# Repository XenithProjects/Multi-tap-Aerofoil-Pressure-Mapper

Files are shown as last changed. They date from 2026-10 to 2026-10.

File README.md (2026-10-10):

# Multi-tap-Aerofoil-Pressure-Mapper
An open-source Multi-tap Aerofoil Pressure Mapper for a NACA 2412 Aerofoil using an ESP32, a PCA9548A I2C Multiplexer and five Sensirion SDP810-500Pa differential pressure sensors.
Adaptable to other aerofoil designs.

20260806_193753(1)

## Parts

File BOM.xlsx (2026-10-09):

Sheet: Sheet1
# | Component | Specification | Qty | Unit (S$) | Total (S$) | Source | Purchased?
1 | ESP32 DevKit V1 | 38-pin, 240 MHz, Wi-Fi + BT, USB-serial | 1 | 4.3 | 4.3 | Taobao | Yes
2 | I2C Multiplexer | TCA9548A breakout, 8-channel | 1 | 0.87 | 0.87 | Taobao | Yes
3 | Sensirion SDP810-125Pa | ±125 Pa, I2C, 16-bit — upper surface taps (U1–U5) | 5 | 12.97 | 64.85 | Taobao
4 | Sensirion SDP810-125Pa | ±125 Pa, I2C — freestream pitot reference | 1 | 12.97 | 12.97 | Taobao
5 | NACA 2412 model (3D print) | PLA, 200 mm chord × 100 mm span, 5 taps pre-modelled | 1 | 0 | 0 | Home
6 | Brass tube stubs | OD 1.5 mm, cut to 10 mm — tap stubs × 8 | 8 | 0.3 | 2.4 | Sim Lim / hardware
7 | Vinyl tubing | ID 1 mm, 3 m roll — tap-to-sensor lines | 1 | 4 | 4 | Shopee
8 | Epoxy adhesive | 2-part low-viscosity, for tap stub sealing | 1 | 3.5 | 3.5 | Hardware store
9 | Breadboard + jumper kit | 830-tie full breadboard + 65-piece jumper set | 1 | 4.34 | 4.34 | Taobao
10 | 4.7 kΩ resistors | Through-hole, I2C pull-ups × 10 | 1 |  | 0
11 | 100 nF decoupling caps | Ceramic through-hole × 10 | 1 |  | 0
12 | USB Micro-B cable | Data + power, 1 m | 1 | 0 | 0 | Home
13 | 5 V USB adapter | 1 A minimum for ESP32 | 1 | 0 | 0 | Home
14 | MicroSD card module + card | SPI, 8 GB card — for offline data logging | 1 | 0.72 | 0.72 | Taobao
15 | Adjustable AoA stand | 3D-printed, protractor scale, ±20° range | 1 | 0 | 0 | Home
16 | Duct fan / desk fan | ≥ 15 m/s freestream at model — borrow if possible | 1 | 0 | 0 | Home
TOTAL ESTIMATED COST |  |  |  |  | 97.95 | Under S$100 budget ✓

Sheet: Sheet2
# | Component | Qty | Unit (S$) | Total (S$) | Source | Purchased?
1 | ESP32-WROOM-32 DevKit V1 | 1
2 | Sensirion SDP810-500Pa - upper taps U1 to U5, lower taps L1 & L2, freestream pitot static reference | 8
5 | PCA9548A 8-channel I2C multiplexer breakout module | 1
6 | NACA 2412 aerofoil model - 3D-printed | 1
7 | Brass tube stubs - OD 1.5 mm, ID 0.8 mm, cut to 10 mm | 16
8 | Vinyl tubing - ID 1 mm, OD 2 mm, 3 m roll | 1
9 | 2-part low-viscosity epoxy adhesive (Araldite Rapid) | 1
10 | Half-size solderless breadboard - 400-tie | 1
11 | Jumper wire kit - male-male and male-female, 65 pieces | 1
12 | 4.7 kOhm resistors | 2
13 | 100 nF ceramic capacitors | 8
14 | 10 uF electrolytic capacitors | 2
15 | USB C cable - 1 m, data-capable | 1
17 | Adjustable angle-of-attack stand - 3D-printed | 1
18 | Pitot tube assembly - 3D-printed | 1
20 | Duct fan or desk fan - minimum 15 m/s freestream velocity at model face | 1
TOTAL ESTIMATED COST |  |  |  | 0 | S$14.32 under budget

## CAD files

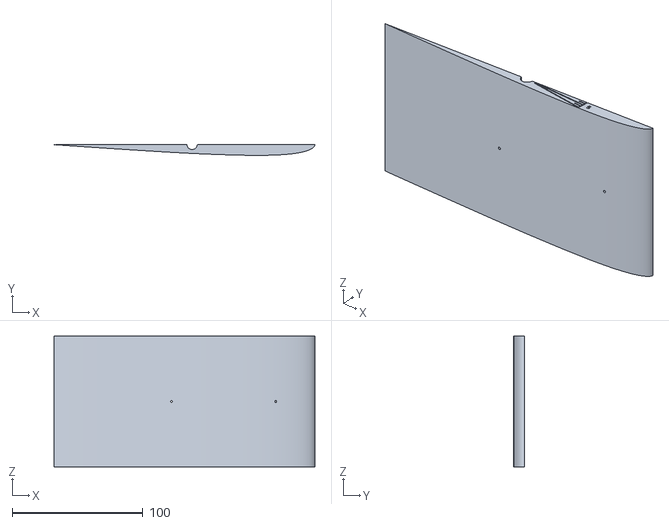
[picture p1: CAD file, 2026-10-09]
.stl Files/Aerofoil w Angle Stand/NACA2412 Airfoil_Lower.stl
199.9 x 8.23 x 100.0

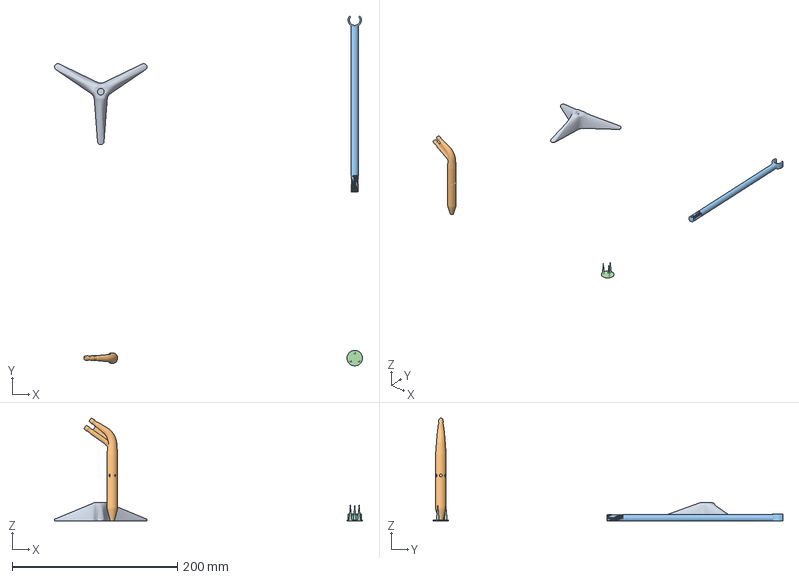
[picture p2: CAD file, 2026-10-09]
.stl Files/Pitot-static Probe.3mf
372.5 x 423.0 x 124.3 mm
Tripod.stl
Pitot-static Head.stl
Stem.stl
string test.stl

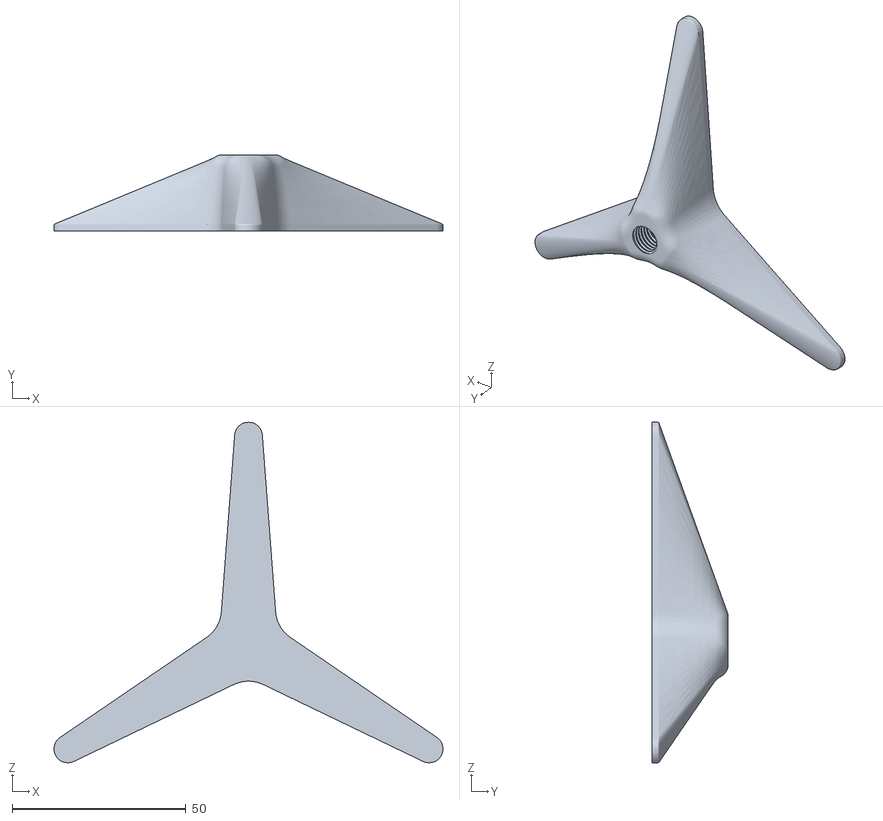
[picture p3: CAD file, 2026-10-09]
.stl Files/Pitot-static Tube/Tripod.stl
111.9 x 22.0 x 98.0

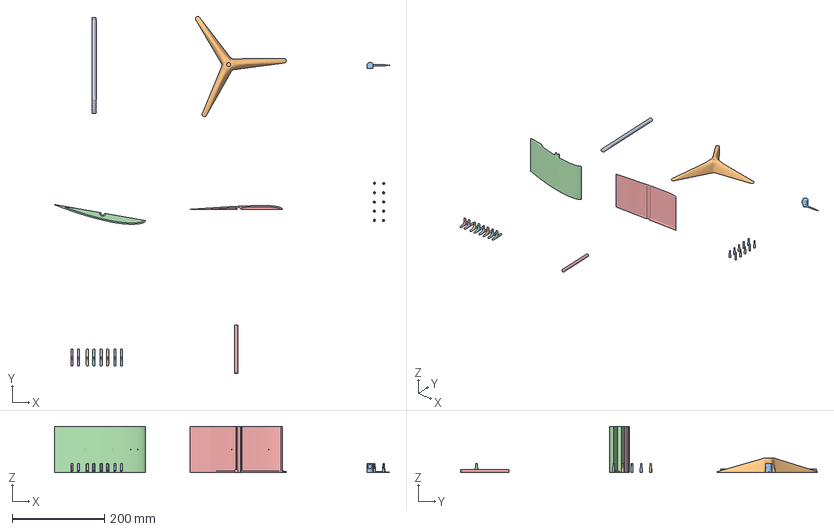
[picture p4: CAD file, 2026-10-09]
.stl Files/Aerofoil w Angle Stand.3mf
724.5 x 773.0 x 100.0 mm
Stem_AF.stl
Tripod_AF.stl
Pointer Joint.stl
NACA2412 Airfoil_Upper.stl
NACA2412 Airfoil_Lower.stl
Vtube Adapter_v3.stl x 10
Vtube T-joint.stl x 8
Dowel_v3.stl

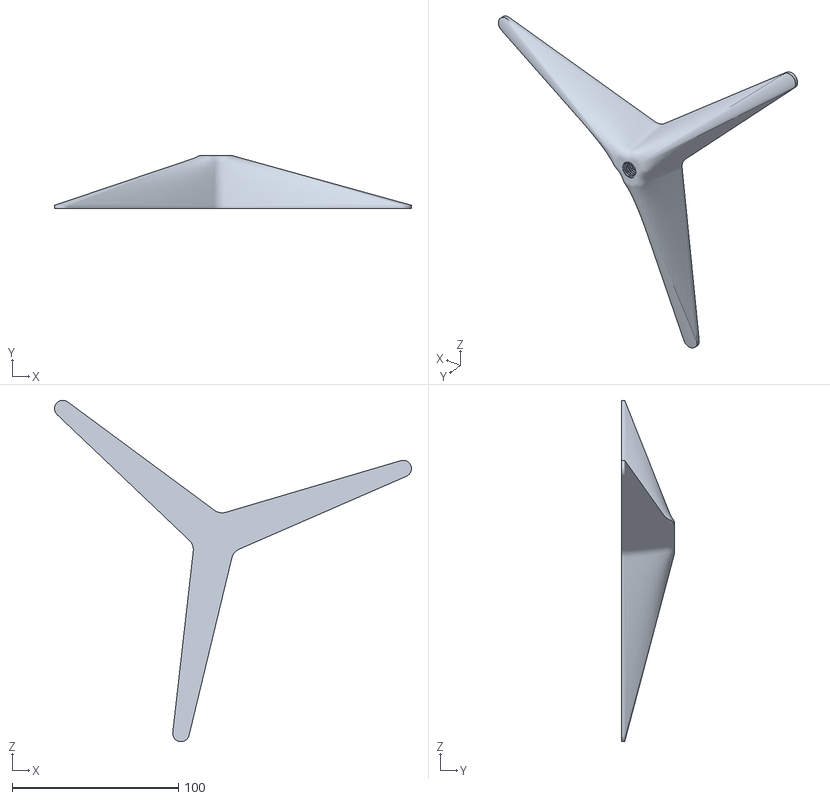
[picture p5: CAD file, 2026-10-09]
.stl Files/Aerofoil w Angle Stand/Tripod_AF.stl
214.7 x 32.0 x 205.3

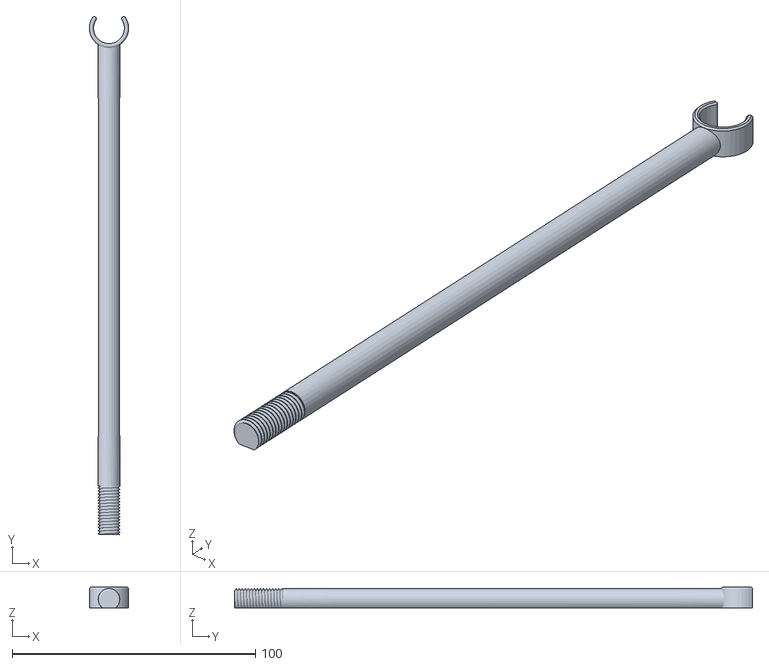
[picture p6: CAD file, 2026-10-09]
.stl Files/Pitot-static Tube/Stem.stl
16.2 x 212.9 x 8.50

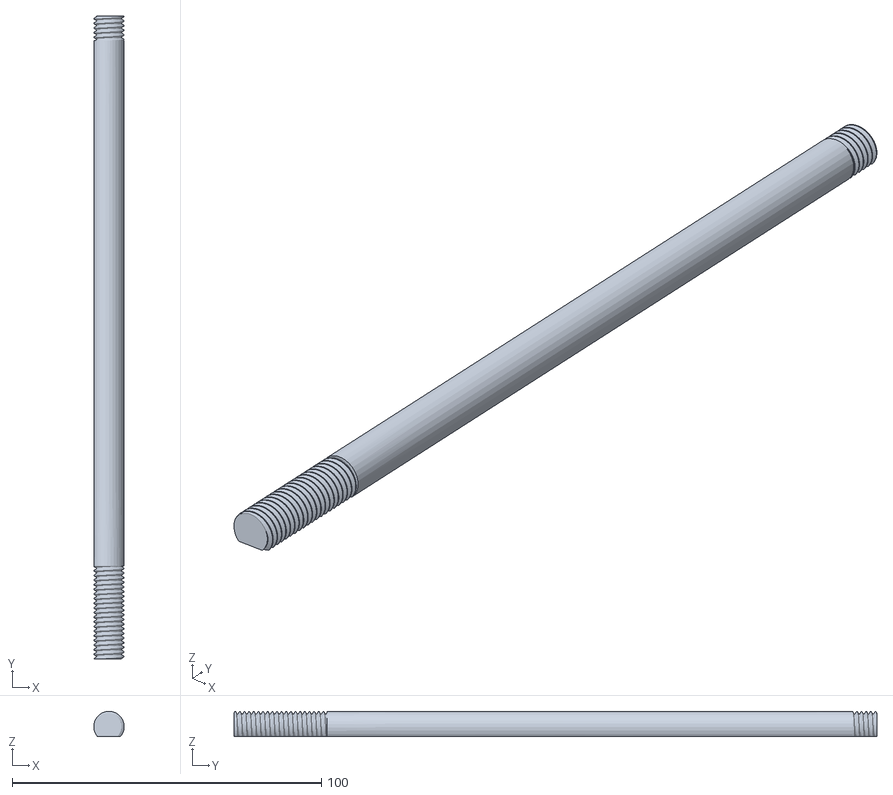
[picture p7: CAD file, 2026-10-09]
.stl Files/Aerofoil w Angle Stand/Stem_AF.stl
9.85 x 207.9 x 8.18

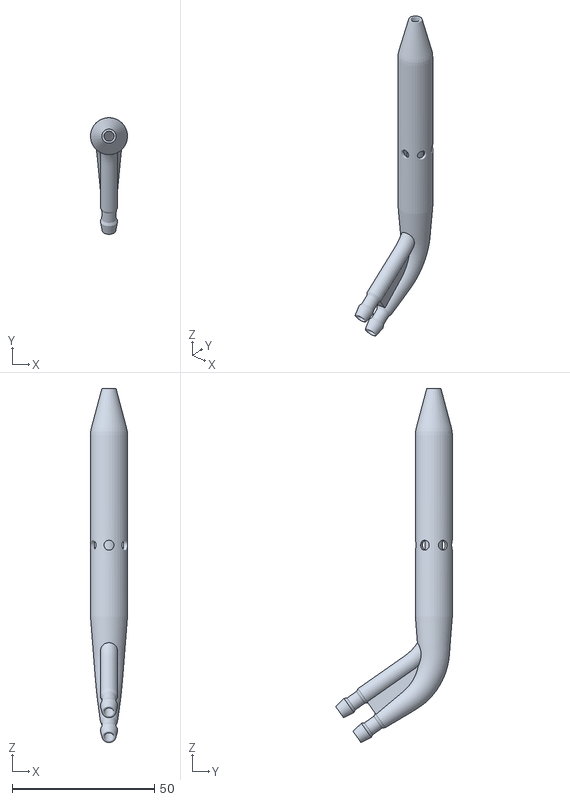
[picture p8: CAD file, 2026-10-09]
.stl Files/Pitot-static Tube/Pitot-static Head.stl
13.0 x 41.0 x 124.3

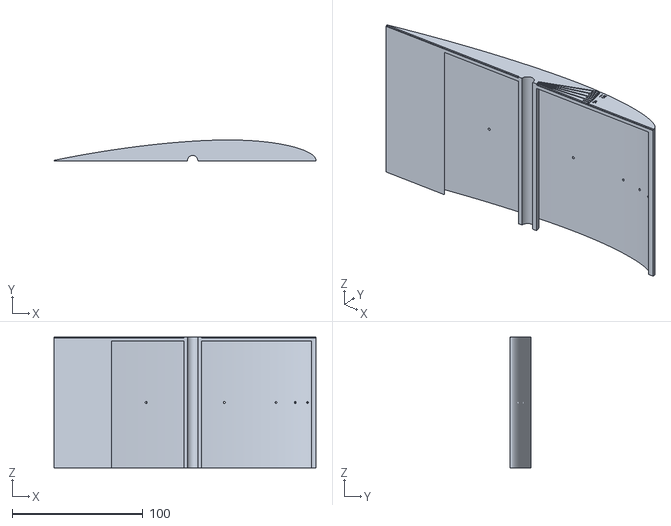
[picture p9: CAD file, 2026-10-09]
.stl Files/Aerofoil w Angle Stand/NACA2412 Airfoil_Upper.stl
200.0 x 16.1 x 100.0

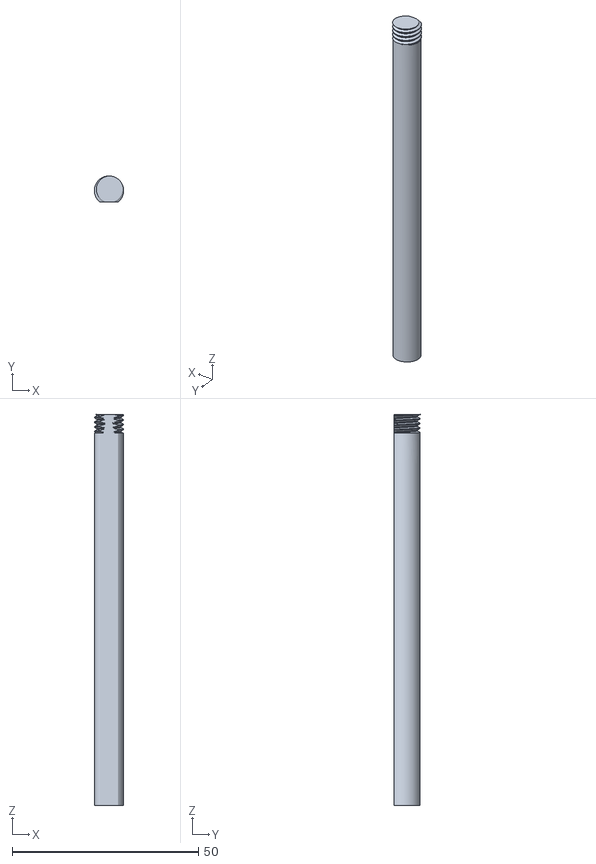
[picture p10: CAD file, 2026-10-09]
.stl Files/Aerofoil w Angle Stand/Dowel_v3.stl
7.87 x 7.02 x 104.9

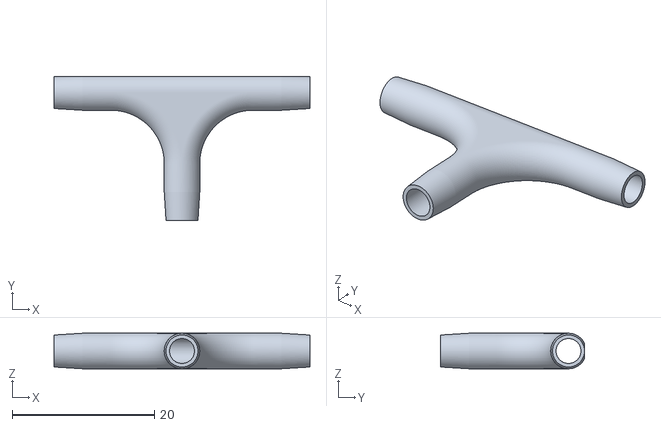
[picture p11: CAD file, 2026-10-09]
.stl Files/Aerofoil w Angle Stand/Vtube T-joint.stl
36.0 x 20.2 x 5.00

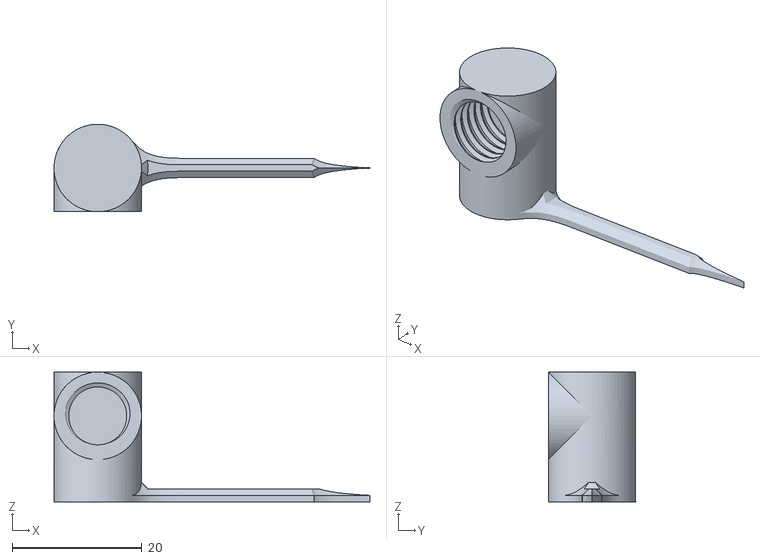
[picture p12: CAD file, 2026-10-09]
.stl Files/Aerofoil w Angle Stand/Pointer Joint.stl
48.8 x 13.5 x 20.0

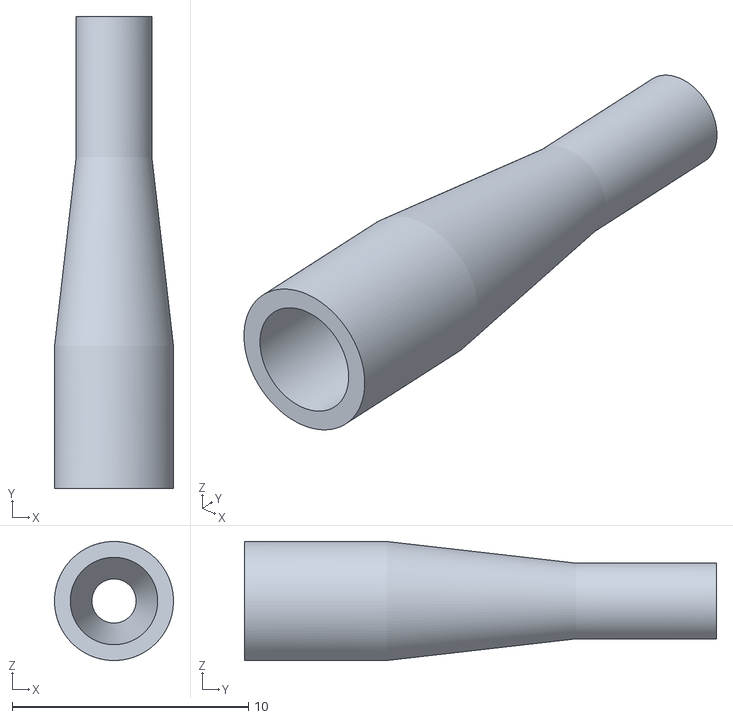
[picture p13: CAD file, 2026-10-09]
.stl Files/Aerofoil w Angle Stand/Vtube Adapter_v3.stl
5.04 x 20.0 x 5.04

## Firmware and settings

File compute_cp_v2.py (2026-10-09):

"""
compute_cp.py

Reads a CSV logged by serial_logger.py (columns: time_ms, P_ch0..P_ch5)
and computes the pressure coefficient Cp at each tap.

Assumes:
  - CH0-CH4 (or however many taps you have wired) are surface pressure taps,
    each measuring (P_tap - P_static_reference).
  - CH5 is the pitot channel, measuring (P_total - P_static_reference) = dynamic
    pressure q_inf, since it shares the same static reference line as the taps.
  - Cp = P_tap_measured / q_inf   (since both sensors reference the same static line,
    the P_static term cancels out algebraically).

Adjust TAP_CHANNELS / PITOT_CHANNEL / tap x/c labels below to match your actual
wiring order before running.

Usage:
    python compute_cp.py aerofoil_run_20260803_143000.csv
    python compute_cp.py aerofoil_run_20260803_143000.csv --start 5 --end 25
"""

import argparse
import sys

import pandas as pd
import matplotlib.pyplot as plt

# --- Configure this to match your actual tap layout ---
# Updated layout: CH0=U1, CH1=U2, CH2=U3, CH3=L1, CH4=REF (pitot). CH5 unused (faulty sensor).
PITOT_CHANNEL = "P_ch4"
TAP_CHANNELS = {
    "P_ch0": {"label": "U1", "surface": "upper", "x_c": 0.025},
    "P_ch1": {"label": "U2", "surface": "upper", "x_c": 0.150},
    "P_ch2": {"label": "U3", "surface": "upper", "x_c": 0.350},
    "P_ch3": {"label": "L1", "surface": "lower", "x_c": 0.150},
}


def main():
    parser = argparse.ArgumentParser(description="Compute Cp distribution from logged sensor data.")
    parser.add_argument("csv_file", help="Path to CSV file from serial_logger.py")
    parser.add_argument("--start", type=float, default=None,
                         help="Start of steady-state averaging window, in seconds from log start")
    parser.add_argument("--end", type=float, default=None,
                         help="End of steady-state averaging window, in seconds from log start")
    parser.add_argument("--out", default="cp_results.csv", help="Output CSV filename for Cp results")
    parser.add_argument("--no-plot", action="store_true", help="Skip generating the Cp plot")
    args = parser.parse_args()

    df = pd.read_csv(args.csv_file)
    df["time_s"] = (df["time_ms"] - df["time_ms"].iloc[0]) / 1000.0

    # Trim to steady-state window if given
    if args.start is not None:
        df = df[df["time_s"] >= args.start]
    if args.end is not None:
        df = df[df["time_s"] <= args.end]

    if df.empty:
        print("No data left after applying --start/--end window. Check your time range.")
        sys.exit(1)

    print(f"Averaging over {len(df)} rows "
          f"({df['time_s'].min():.1f}s to {df['time_s'].max():.1f}s)\n")

    q_inf = df[PITOT_CHANNEL].mean()
    q_std = df[PITOT_CHANNEL].std()
    print(f"Freestream dynamic pressure q_inf = {q_inf:.3f} Pa (std dev {q_std:.3f} Pa)")

    if q_inf <= 0:
        print("WARNING: q_inf is zero or negative - check pitot wiring/orientation, "
              "or that airflow is actually running.")

    results = []
    for ch, meta in TAP_CHANNELS.items():
        if ch not in df.columns:
            print(f"WARNING: {ch} not found in CSV columns, skipping.")
            continue

        p_mean = df[ch].mean()
        p_std = df[ch].std()
        cp = p_mean / q_inf if q_inf else float("nan")

        results.append({
            "channel": ch,
            "label": meta["label"],
            "surface": meta["surface"],
            "x_c": meta["x_c"],
            "P_mean_Pa": round(p_mean, 3),
            "P_std_Pa": round(p_std, 3),
            "Cp": round(cp, 4),
        })

    results_df = pd.DataFrame(results).sort_values(["surface", "x_c"])
    print("\n--- Cp Results ---")
    print(results_df.to_string(index=False))

    results_df.to_csv(args.out, index=False)
    print(f"\nSaved results to {args.out}")

    if not args.no_plot:
        fig, ax = plt.subplots(figsize=(7, 5))
        for surface, marker in [("upper", "o-"), ("lower", "s-")]:
            sub = results_df[results_df["surface"] == surface]
            if not sub.empty:
                ax.plot(sub["x_c"], sub["Cp"], marker, label=f"{surface} surface")

        ax.invert_yaxis()  # aerodynamic convention: Cp axis flipped
        ax.set_xlabel("x/c")
        ax.set_ylabel("Cp")
        ax.set_title("NACA 2412 Pressure Distribution")
        ax.legend()
        ax.grid(True, alpha=0.3)
        fig.tight_layout()

        plot_file = args.out.replace(".csv", "_plot.png")
        fig.savefig(plot_file, dpi=150)
        print(f"Saved plot to {plot_file}")


if __name__ == "__main__":
    main()

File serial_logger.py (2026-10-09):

"""
serial_logger.py

Logs CSV pressure data streamed from the ESP32 (aerofoil_scanner_serial.ino)
to a local CSV file, for later Cp post-processing.

Requires: pip install pyserial

Usage:
    python serial_logger.py --port COM5
    python serial_logger.py --port /dev/ttyUSB0 --duration 30
"""

import argparse
import csv
import sys
import time
from datetime import datetime

import serial


def main():
    parser = argparse.ArgumentParser(description="Log SDP810 mux data over serial to CSV.")
    parser.add_argument("--port", required=True, help="Serial port, e.g. COM5 or /dev/ttyUSB0")
    parser.add_argument("--baud", type=int, default=115200, help="Baud rate (default 115200)")
    parser.add_argument("--outfile", default=None, help="Output CSV filename")
    parser.add_argument("--duration", type=float, default=None,
                         help="Seconds to log before auto-stopping (default: run until Ctrl+C)")
    args = parser.parse_args()

    outfile = args.outfile or f"aerofoil_run_{datetime.now().strftime('%Y%m%d_%H%M%S')}.csv"

    print(f"Connecting to {args.port} at {args.baud} baud...")
    ser = serial.Serial(args.port, args.baud, timeout=1)
    time.sleep(2)  # allow ESP32 to reset after serial connection opens

    header_written = False
    start_time = time.time()
    row_count = 0

    with open(outfile, "w", newline="") as f:
        writer = csv.writer(f)
        print(f"Logging to {outfile} ... Ctrl+C to stop\n")

        try:
            while True:
                if args.duration is not None and (time.time() - start_time) > args.duration:
                    print(f"\nReached duration limit of {args.duration}s, stopping.")
                    break

                raw = ser.readline().decode(errors="ignore").strip()
                if not raw:
                    continue

                # Only process our tagged data/header rows; ignore diagnostic '#' lines
                if raw.startswith("DATA,"):
                    fields = raw[len("DATA,"):].split(",")

                    if fields[0] == "time_ms" and not header_written:
                        writer.writerow(fields)
                        header_written = True
                        print("Header:", ",".join(fields))
                        continue

                    if fields[0] == "time_ms":
                        continue  # duplicate header line, skip

                    writer.writerow(fields)
                    row_count += 1
                    if row_count % 10 == 0:
                        print(f"[{row_count} rows] {raw}")
                else:
                    # Startup/diagnostic messages from the ESP32
                    print(raw)

        except KeyboardInterrupt:
            print("\nStopped by user.")

    print(f"\nDone. {row_count} data rows written to {outfile}")


if __name__ == "__main__":
    try:
        main()
    except serial.SerialException as e:
        print(f"Serial error: {e}")
        print("Check that the port name is correct and no other program (e.g. Arduino Serial Monitor) has it open.")
        sys.exit(1)

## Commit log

2026-10-09 Add files via upload
    Added code for ESP32
2026-10-09 Add files via upload
    Added .stl and .3mf files for aerofoil and angle stand
    [Aerofoil w Angle Stand.3mf, Dowel_v3.stl, NACA2412 Airfoil_Lower.stl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]
2026-10-09 Add files via upload
    Added .stl and .3mf files for pitot static probe
    [Pitot-static Head.stl, Pitot-static Probe.3mf, Stem.stl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]
2026-10-09 Add files via upload
    Added BOM.xlsx template
    [BOM.xlsx]
2026-10-09 Rename Dowel_v3.stl to .stl Files/Dowel_v3.stl
    [Dowel_v3.stl]
2026-10-10 Add files via upload
    Added all relevant .stl files
    [Dowel_v3.stl, NACA2412 Airfoil_Lower.stl, NACA2412 Airfoil_Upper.stl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]
2026-10-10 Add files via upload
    Added relevant .stl files
    [Pitot-static Head.stl, Stem.stl, Tripod.stl]
2026-10-10 Add files via upload
    Added .3mf files
    [Aerofoil w Angle Stand.3mf, Pitot-static Probe.3mf]
2026-10-10 Add files via upload
    Added logged test data for a NACA 2412 aerofoil.
    [Final Data.xlsx]
